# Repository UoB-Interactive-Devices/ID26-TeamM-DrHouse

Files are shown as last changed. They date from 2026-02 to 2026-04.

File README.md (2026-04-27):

# ID26-TeamM-DrHouse

## Team

<p align="center">
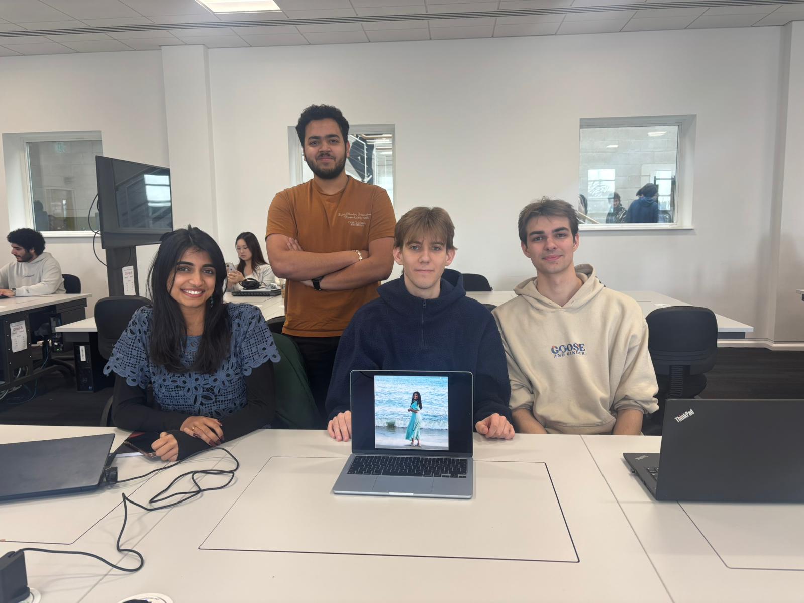
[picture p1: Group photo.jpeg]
Our team photo
  
  <br/>
  Our team photo
</p>

## Team Members
Deeksha Subramanya
<br/>
Ebin Toly
<br/>
Hugh Kiggell
<br/>
Luke Trott
<br/>
Thushi Thulasiraj

## Ideation
Window Cleaning Snail
 Image created by nano banana

Smart tap
 Image created by nano banana

Spider wall climbing robot that dusts hard to reach areas
 Image created by nano banana

## Our Interactive device
Our device is a snail that will clean and make your windows sparkling. The user charges the device. Remove the shell and fill up with water. Press the on off button at the back to start. Then simply place it on the window and it will start tracing and cleaning. The snail will have ergonomic fingerprints to encourage a correct grip. There will be a weighted hose inside the shell to spray misted water onto the window via the snail’s mouth. Once complete, the snail will beep thrice, indicating it is time to be removed.

## Design Prototype

<table>
  <tr>
    <td align="center">
      snail_cardboard1<br/>
      First prototype made of foam, not to scale.
    </td>
    <td align="center">
      snail_cardboard2
    </td>
  </tr>
</table>

<br/>

<table>
  <tr>
    <td align="center">
      snail_clay1<br/>
      Second prototype made of clay, not to scale.
    </td>
    <td align="center">
      snail_clay2<br/>
      Final design intended to be double the current size.
    </td>
  </tr>
</table>

## Questionaire

https://forms.office.com/Pages/DesignPageV2.aspx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
https://forms.office.com/Pages/DesignPageV2.aspx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

To send out: https://forms.office.com/Pages/ResponsePage.aspx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

## In person Questionaire - (Device testing)

[https://forms.office.com/Pages/DesignPageV2.aspx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](https://forms.office.com/Pages/DesignPageV2.aspx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)

To send out: https://forms.office.com/Pages/ResponsePage.aspx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

## SUS Test:

https://forms.office.com/Pages/DesignPageV2.aspx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

To send out: https://forms.office.com/Pages/ResponsePage.aspx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

## Consent Form

https://forms.office.com/Pages/DesignPageV2.aspx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

To send out: https://forms.office.com/Pages/ResponsePage.aspx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

## Risk Assesments

[Testing and Developing Rover](https://uob.sharepoint.com/:w:/r/teams/grp-grp-interactivedevices2025-2026/Shared%20Documents/Group%20M%20(Dr.%20House)%20-%20Snail%20Cleaner/Risk%20Assessment%C2%A0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)

[Demo Day](https://uob.sharepoint.com/:w:/r/teams/grp-grp-interactivedevices2025-2026/Shared%20Documents/Group%20M%20(Dr.%20House)%20-%20Snail%20Cleaner/Risk%20Assessment%C2%A0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)

## Documentation
Full report available on Overleaf check it out here:
[https://www.overleaf.com/read/fzhzwbgzmqft#be855f](https://www.overleaf.com/9472865782wmpkmnqygdsy#4a67b0)

## Video

https://uob.sharepoint.com/:v:/r/teams/grp-grp-interactivedevices2025-2026/Shared%20Documents/Group%20M%20(Dr.%20House)%20-%20Snail%20Cleaner/DrHouse_Video.MOV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

## Timeline

https://docs.google.com/document/d/1-UH61Pvg8FrAMAUsMvd9KDbhnIRM3Y1bEEfzOIujOz8/edit?usp=sharing

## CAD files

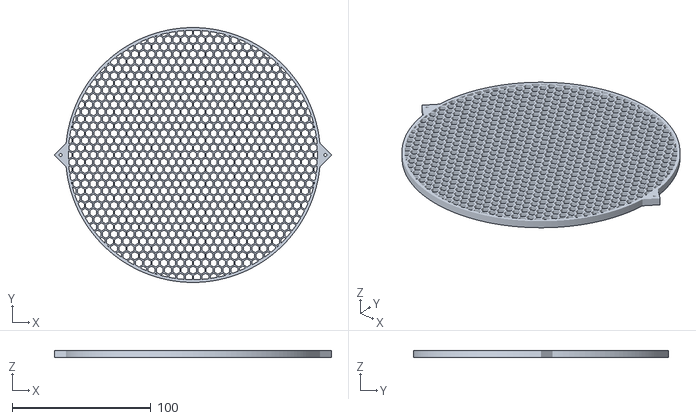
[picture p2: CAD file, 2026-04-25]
Lid.stl
200.0 x 184.0 x 5.00

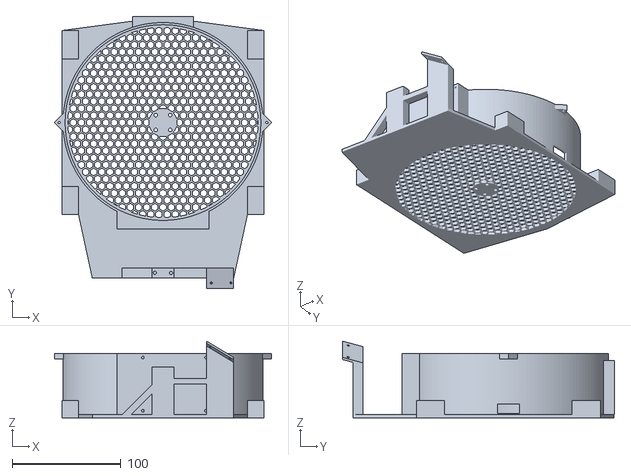
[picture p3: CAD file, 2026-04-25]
Final_Design.stl
200.0 x 250.2 x 70.6

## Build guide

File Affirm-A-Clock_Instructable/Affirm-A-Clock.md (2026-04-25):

# Instructable: Affirm-A-Clock
**Build an affirmation-based wellbeing alarm clock!**



## 1. Project Summary

Welcome to the Affirm-A-Clock project! This guide will walk you through building a Raspberry Pi-powered robotic wellness coach designed to break the "snooze" button habit and optimise your morning routine. Smartphone alarms are far too easy to ignore. - the classic snooze button actually prolongs sleep inertia, leaving you groggy and disoriented. To tackle this, Affirm-A-Clock forces you to combine physical activity with positive mental health behaviors before the alarm can be silenced. 
**How the Routine Works:** 
* **Wake Up & Move:** When the alarm triggers, you must physically get out of bed and open your curtains to experience natural sunlight. Once the alarm is stopped, the robot tells you your affirmation for the day using a Bluetooth speaker. 
* **Write an Affirmation:** You then write this positive daily affirmation directly onto your window, and underline it using dry-erase markers. 
* **Verification:** You stick the robot to the window (using fan-powered suction), where it follows the line (using HuskyLens line detection) to track your writing and confirms the completion of your handwritten task.
* **Reward & Clean:** The robot congratulates you and announces your new daily streak. Finally, you wipe the window clean, which builds a daily habit of room tidiness (which is tied to mental wellbeing). 

This guide covers the complete mechanical, electrical, and software integration required to build your own Affirm-A-Clock!

**Please Note: As this device is a proof of concept, the window suction mechanism does not yet function entirely. The assembly instructions include its installation for completeness, but strict safety measures and careful setup are required to operate it safely.  If you intend to use the propeller, ensure the safety mesh is attached, that the robot is in an enclosed space and that you are wearing protective gear (goggles, gloves, and lab coat).**

---

## 2. List of Resources Required

### Microcontrollers & Logic
* **1x** Raspberry Pi 4 (Running Raspberry Pi OS)
* **1x** DFRobot HuskyLens (AI Vision Camera)
* **1x** Bluetooth Speaker (For TTS Audio)
* **1x** ArduCam 8MP Camera V2.3

### Motors & Driving
* **1x** HW-095 Motor Controller Driver
* **4x** DC Gear Motors & Wheels (6cm diameter including tires)
* **1x** Brushless DC (BLDC) Drone Motor
* **1x** Electronic Speed Controller (ESC)
* **1x** 7" tri-blade plastic propeller
### Power & Hardware
* **1x** External power supply (6v) to power the wheel motors
* **1x** External power supply (24v) to power the propeller drone motor
* **1x** USB-c power cable to power Raspberry Pi
* Jumper wires (Female-to-Female, Male-to-Female)
* Zip-ties, hot glue or electrical tape for cable management and mounting
* Mounting screws:
	* **10x** 8mm M3 screws (Huskylens, drone motor, HW-095 motor driver)
	* **4x** 8mm M2.5 screws (Raspberry Pi 4)
	* **2x** 16mm M2 screws + M2 nuts (Protective mesh)
	* **2x** 8mm M2 screws + M2 nuts (ArduCam)
	* **1x** M3 nut (propeller)

---

## 3. Pinout & Wiring Guide

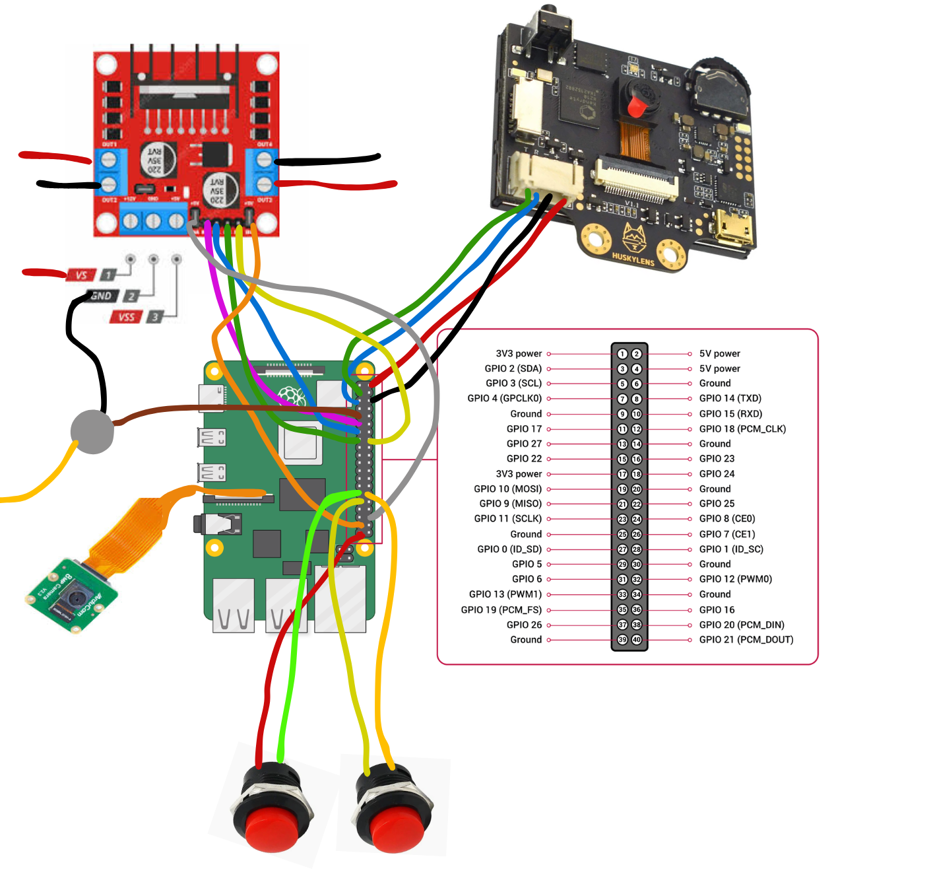
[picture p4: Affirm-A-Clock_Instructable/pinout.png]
My Pinout Diagram


For the data and PWM signals to function, the Raspberry Pi must share a **Common Ground** with both the drone motor's ESC and the HW-095 motor controller. 

### The Wiring Table

| Component | Pi Physical Pin | Pi BCM (GPIO) | Purpose |
| :--- | :--- | :--- | :--- |
| **ESC (Drone Motor)** | Pin 12 | GPIO 18 | Hardware PWM Signal (50Hz) |
| **ESC Ground** | Pin 14 | GND | Signal Ground |
| **HW-095 ENA** | Pin 32 | GPIO 12 | Right Motor PWM Speed |
| **HW-095 IN1** | Pin 33 | GPIO 13 | Right Motor Direction A |
| **HW-095 IN2** | Pin 22 | GPIO 25 | Right Motor Direction B |
| **HW-095 ENB** | Pin 37 | GPIO 26 | Left Motor PWM Speed |
| **HW-095 IN3** | Pin 13 | GPIO 27 | Left Motor Direction A |
| **HW-095 IN4** | Pin 8 | GPIO 14 | Left Motor Direction B |
| **HuskyLens SDA** | Pin 3 | GPIO 2 | I2C Data Line |
| **HuskyLens SCL** | Pin 5 | GPIO 3 | I2C Clock Line |
| **Button 1 Terminal A** | Pin 39 | GND | Button 1 Ground |
| **Button 1 Terminal B** | Pin 29 | GPIO 5 | Button 1 Signal Input |
| **Button 2 Terminal A** | Pin 31 | GPIO 6 | Button 2 Signal Input |
| **Button 2 Terminal B** | Pin 30 | GND | Button 2 Ground |

If you want to use the drone motor, ensure you use an ESC, and then connect the motor input signal to the Pi's pin 12, and add the motor's ground connection to the common ground with the pi and HW-095

---

## 5. CAD Design & Mechanical Assembly

The CAD .stl files for the robot frame and the protective lid are hosted on GitHub, accessible here:
-> **https://github.com/UoB-Interactive-Devices/ID26-TeamM-DrHouse**

### Assembly Steps:
1. **Print the Frame:** Start by 3D printing the robot frame and the protective mesh lid.
2. **Wire & Mount the Pi:** Pre-wire the Raspberry Pi 4, and then securely screw it into its mounting points on front of the frame.
3. **Attach the Cameras:** Screw the Arducam into place in its stand, and then mount the HuskyLens at the front of the frame so it has a clear view of the environment.
4. **Mount the Wheels:** Using a hot glue gun, firmly glue the DC wheel motors down onto their designated platforms on the frame.
5. **Install the Motor Controller:** Screw the HW-095 motor driver into the back of the frame. 
6. **Cable Management:** Route all of your wires and cables around the frame of the robot, ensuring they are tucked away from the wheels. You can position the buttons using glue or tape as well.
7. **Mount the Drone Motor:** Securely screw the drone motor into its designated mount in the center of the frame.
8. **Attach the Propeller & Safety Lid:** Carefully attach the propeller to the drone motor and secure using a nut. Immediately screw the protective mesh lid on top to safely enclose the propeller blades.

---

## 6. Software Setup & Configuration

### Install Dependencies
Run these commands in your terminal to install the necessary libraries for the audio engines:
```bash
sudo apt update
sudo apt install build-essential unzip python3-setuptools mpg123 sox -y
pip3 install gTTS gpiozero --break-system-packages
```
----------

## 7. The Code & Software Architecture

All the Python scripts and required libraries are hosted on GitHub. You can download the entire code repository, including the `robot_core.py` script and any necessary libraries, here:
-> **https://github.com/UoB-Interactive-Devices/ID26-TeamM-DrHouse**

### How the Robot Core Code Works
The `robot_core.py` handles hardware interrupts, local AI driving, cloud-based OCR, and Google Drive syncing. Here is a breakdown of its systems:

* **Hardware Inputs & State Management:** The script uses the `gpiozero` library to manage the physical Power and Action buttons. It runs a dedicated background thread to monitor button presses and handle debounce (so that there's only one input per one button press). 
* **Audio & TTS:** The code uses Google Text-to-Speech (`gTTS`) to generate the robot's voice, and caches the audio files locally to ensure immediate playback. To solve the issue where the Pi's audio driver 'sleeps' and misses the beginning of a sound file, the a short, silent 10Hz tone is played immediately before the real audio.
* **Driving and HuskyLens:** The Pi communicates with the HuskyLens with I2C to receive line-tracking vector data (`xHead`, `yHead`, `xTail`). The code calculates the "slant" of the line and categorises the robot into one of 5 states (e.g., straight, soft-turn, hard-correction). It then uses PWM to drive the HW-095 motor controller, adjusting the speed of the left and right wheels to follow the path.
* **Machine Vision & OCR:** While driving, a background thread uses `Picamera2` to snap photos of the floor every 0.5 seconds. Once the run finishes, the code takes these overlapping photos, stitches them together into image strips using the `PIL` (Pillow) library, boosts the contrast, and sends them to a multimodal AI model using the OpenRouter API.
* **AI Evaluation (The Judge):** Once the OCR returns the text it read from the floor, the script makes a second API call to an LLM. It passes the target affirmation and the detected text, asking the LLM to act as a lenient judge to determine a "PASS" or "FAIL", ignoring minor spelling or handwriting errors.
* **Google Drive Sync & Streak Tracking:** If you pass, the script uses the `google-auth` library to connect to your personal Google Drive. It reads the final line of an `affirmation_log.txt` file to calculate how many consecutive days you have completed the task, increments your streak by 1, and uploads the appended log back to the cloud. The robot then announces your new streak.

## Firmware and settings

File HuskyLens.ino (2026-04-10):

#include "HUSKYLENS.h"
#include "Wire.h"
#include <WiFi.h> // --- NEW: Wi-Fi Library ---

HUSKYLENS huskylens;

// ==========================================
// --- THE MASTER SWITCH ---
// Set to true for Wi-Fi. Set to false for USB Cable!
bool useWiFi = false; 
// ==========================================

// --- NEW: Wi-Fi Settings (THE ROBOT IS NOW THE ROUTER) ---
const char* ap_ssid = "Tank_Robot";
const char* ap_pass = "12345678";

// When a laptop connects to an ESP32, it almost ALWAYS gets this IP:
const char* hostIP = "192.168.4.2"; 
const uint16_t port = 5204;
WiFiClient client;

// --- Motor Wiring ---
int ENA = 32; int IN1 = 33; int IN2 = 25; 
int ENB = 14; int IN3 = 26; int IN4 = 27; 

// --- Joystick Pins ---
int joyXPin = 35; 
int joyYPin = 34; 

// --- TANK STEERING SETTINGS: THE LOW RIDER TEST ---
int autoBaseSpeed = 85;         // The absolute crawl. 

// SOFT TURNS
int autoSoftInner = 85;         // Pushing the floor!
int autoSoftOuter = 110;        // Just enough difference to steer

// HARD TURNS 
int autoHardPush = 120;         // Push forward harder into the turn!
int autoHardRev = -120;         // Pull backward gently just to help pivot

// --- Odometry Variables ---
float posX = 0.0, posY = 0.0, heading = 1.5708;
float moveDistance = 2.0; 

// --- LINE TRACKING MEMORY & DIAGNOSTICS ---
unsigned long lastDetectionTime = 0;
const unsigned long MEMORY_TIMEOUT = 200; 
int robotState = 0; // 0=Stop, 1=Strt, 2=SoftL, 3=SoftR, 4=HardL, 5=HardR

// --- NEW LOGGING VARIABLES ---
int lastTipX = 160; 
int lastSlant = 0;              
const char* activeMode = "TIP"; 

// --- NEW: WI-FI RECONNECT TIMER ---
unsigned long lastWiFiTry = 0; 

void setup() {
    Serial.begin(115200);
    
    // --- MODE SELECTION SETUP ---
    if (useWiFi) {
        Serial.println("Starting Robot Hotspot...");
        WiFi.softAP(ap_ssid, ap_pass);
        Serial.print("Robot Hotspot Created! Robot IP is: ");
        Serial.println(WiFi.softAPIP()); 
        Serial.println("Wi-Fi network is active in the background.");
    } else {
        Serial.println("Wi-Fi OFF. Using USB Serial Cable for data.");
    }

    Wire.begin(21, 22);
    Wire.setTimeOut(100);

    pinMode(ENA, OUTPUT); pinMode(IN1, OUTPUT); pinMode(IN2, OUTPUT);
    pinMode(ENB, OUTPUT); pinMode(IN3, OUTPUT); pinMode(IN4, OUTPUT);
    stopMotors();

    delay(3000); 
    while (!huskylens.begin(Wire)) {
        Serial.println("TRAPPED: Cannot find HuskyLens!"); 
        delay(1000); 
    }
    Serial.println("Tank-Steer Hybrid System Ready!");
    Serial.println("--- DIAGNOSTICS STARTED ---");
}

void loop() {
    // --- NON-BLOCKING AUTO-RECONNECT (ONLY IF WIFI IS ON) ---
    if (useWiFi && !client.connected() && (millis() - lastWiFiTry > 2000)) {
        client.connect(hostIP, port);
        lastWiFiTry = millis(); 
    }

    // 1. READ JOYSTICK
    int joyX = analogRead(joyXPin);
    int joyY = analogRead(joyYPin);
    
    int mappedX = map(joyX, 0, 4095, 180, -180); 
    int mappedY = map(joyY, 0, 4095, -180, 180);

    // 2. CHECK FOR MANUAL OVERRIDE
    if (false) { // Joystick disabled
        int leftSpeed = constrain(mappedY + mappedX, -255, 255);
        int rightSpeed = constrain(mappedY - mappedX, -255, 255);
        setLeftMotor(leftSpeed);
        setRightMotor(rightSpeed);
        robotState = 0; 
    } 
    // 3. AUTO-MODE
    else {
        if (!huskylens.request()) {
            Serial.println("I2C ERROR - Hard Resetting Bus...");
            stopMotors();
            
            Wire.end(); delay(100); 
            Wire.begin(21, 22); delay(100);
            huskylens.begin(Wire); 
        } 
        
        else if (huskylens.available()) {
            while (huskylens.available()) {
                HUSKYLENSResult result = huskylens.read();
                if (result.command == COMMAND_RETURN_ARROW) {
                    
                    int tipX = result.xTarget;
                    int tipY = result.yTarget;
                    int tailX = result.xOrigin;
                    
                    lastTipX = tipX; 
                    lastDetectionTime = millis();
                    
                    // --- THE HYBRID LOOK-AHEAD STRATEGY ---
                    if (tipY < 60) { 
                        activeMode = "TIP"; 
                        lastSlant = 0;      
                        
                        if (tipX < 100) { robotState = 4; } 
                        else if (tipX >= 100 && tipX < 150) { robotState = 2; } 
                        else if (tipX > 170 && tipX <= 220) { robotState = 3; } 
                        else if (tipX > 220) { robotState = 5; } 
                        else { robotState = 1; } 
                    } 
                    else {
                        activeMode = "VEC"; 
                        int slant = tipX - tailX; 
                        lastSlant = slant;  
                        
                        if (tipX > 250) { robotState = 5; }
                        else if (tipX < 70) { robotState = 4; }
                        else if (slant < -40) { robotState = 4; } 
                        else if (slant >= -40 && slant < -15) { robotState = 2; } 
                        else if (slant > 15 && slant <= 40) { robotState = 3; } 
                        else if (slant > 40) { robotState = 5; } 
                        else { robotState = 1; } 
                    }
                }
            }
        }

        // 4. MOTOR EXECUTION 
        if (millis() - lastDetectionTime < MEMORY_TIMEOUT) {
            
            if (robotState == 4) { 
                setLeftMotor(autoHardRev); 
                setRightMotor(autoHardPush);
                Serial.printf("[%s] TipX: %3d | Slant: %4d | HARD L | L: %4d | R: %4d\n", activeMode, lastTipX, lastSlant, autoHardRev, autoHardPush);
            } 
            else if (robotState == 2) { 
                setLeftMotor(autoSoftInner); 
                setRightMotor(autoSoftOuter);
                Serial.printf("[%s] TipX: %3d | Slant: %4d | SOFT L | L: %4d | R: %4d\n", activeMode, lastTipX, lastSlant, autoSoftInner, autoSoftOuter);
            } 
            else if (robotState == 3) { 
                setLeftMotor(autoSoftOuter);
                setRightMotor(autoSoftInner);
                Serial.printf("[%s] TipX: %3d | Slant: %4d | SOFT R | L: %4d | R: %4d\n", activeMode, lastTipX, lastSlant, autoSoftOuter, autoSoftInner);
            } 
            else if (robotState == 5) { 
                setLeftMotor(autoHardPush);
                setRightMotor(autoHardRev);
                Serial.printf("[%s] TipX: %3d | Slant: %4d | HARD R | L: %4d | R: %4d\n", activeMode, lastTipX, lastSlant, autoHardPush, autoHardRev);
            } 
            else if (robotState == 1) { 
                setLeftMotor(autoBaseSpeed);
                setRightMotor(autoBaseSpeed);
                Serial.printf("[%s] TipX: %3d | Slant: %4d | STRT   | L: %4d | R: %4d\n", activeMode, lastTipX, lastSlant, autoBaseSpeed, autoBaseSpeed);
            }
            
            // --- DEAD RECKONING ODOMETRY ---
            if (robotState == 1) { 
                posX += cos(heading) * 1.0;  
                posY += sin(heading) * 1.0; 
            } 
            else if (robotState == 2) { 
                heading += 0.002;            
                posX += cos(heading) * 0.8; 
                posY += sin(heading) * 0.8; 
            } 
            else if (robotState == 3) { 
                heading -= 0.002; 
                posX += cos(heading) * 0.8; 
                posY += sin(heading) * 0.8; 
            } 
            else if (robotState == 4) { 
                heading += 0.0075;             
            } 
            else if (robotState == 5) { 
                heading -= 0.0075; 
            }

            // ==========================================
            // --- MANUAL DATA ROUTING ---
            // ==========================================
            if (useWiFi) {
                // Send over Wi-Fi
                if (client.connected()) {
                    client.print("DATA:");
                    client.print(posX);
                    client.print(",");
                    client.println(posY);
                }
            } else {
                // Send over USB Cable
                Serial.print("DATA:");
                Serial.print(posX);
                Serial.print(",");
                Serial.println(posY);
            }
            // ==========================================
            
        } else {
            stopMotors();
            robotState = 0; 
            Serial.println("!!! CAMERA LOST LINE - MOTORS STOPPED !!!");
        }
    }
    delay(20); 
}

// --- UNIVERSAL MOTOR FUNCTIONS ---
void setLeftMotor(int speed) {
    if (speed > 0) {
        digitalWrite(IN1, HIGH); digitalWrite(IN2, LOW); analogWrite(ENA, speed);
    } else if (speed < 0) {
        digitalWrite(IN1, LOW); digitalWrite(IN2, HIGH); analogWrite(ENA, abs(speed));
    } else {
        digitalWrite(IN1, LOW); digitalWrite(IN2, LOW); analogWrite(ENA, 0);
    }
}

void setRightMotor(int speed) {
    if (speed > 0) {
        digitalWrite(IN3, HIGH); digitalWrite(IN4, LOW); analogWrite(ENB, speed);
    } else if (speed < 0) {
        digitalWrite(IN3, LOW); digitalWrite(IN4, HIGH); analogWrite(ENB, abs(speed));
    } else {
        digitalWrite(IN3, LOW); digitalWrite(IN4, LOW); analogWrite(ENB, 0);
    }
}

void stopMotors() {
    setLeftMotor(0); setRightMotor(0);
}

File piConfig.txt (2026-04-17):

[all]
# --- VIDEO & VNC FIX ---
# Enable the video driver so RealVNC has a screen to capture
dtoverlay=vc4-kms-v3d
max_framebuffers=2

# --- YOUR HARDWARE ---
# Enable I2C for your HuskyLens and Camera
dtparam=i2c_arm=on
dtparam=i2c_arm_baudrate=400000
enable_uart=1
dtoverlay=imx219

# --- PI 4 AUDIO FIX ---
dtparam=audio=on
audio_pwm_mode=2
dtoverlay=audremap,pins_12_13

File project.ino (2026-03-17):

#include <ESP32Servo.h>

Servo droneMotor;
const int escPin = 13;

const int enA = 32; const int in1 = 33; const int in2 = 25;
const int enB = 26; const int in3 = 27; const int in4 = 14;

int power = 1000; 

void setup() {
  Serial.begin(115200);
  
  pinMode(enA, OUTPUT); pinMode(in1, OUTPUT); pinMode(in2, OUTPUT);
  pinMode(enB, OUTPUT); pinMode(in3, OUTPUT); pinMode(in4, OUTPUT);
  
  droneMotor.attach(escPin, 1000, 2000);
  stopAll(); // Start all stopped
  
  Serial.println("System Arming. Wait 3s");
  delay(3000);
  Serial.println("Commands: 'G' = Go Faster, 'S' = EMERGENCY STOP");
}

void loop() {
  if (Serial.available() > 0) {
    char cmd = Serial.read();

    if (cmd == 'g' || cmd == 'G') {
      power = constrain(power + 100, 1000, 2000);
      updateMotors();
    } 
    else if (cmd == 's' || cmd == 'S') {
      stopAll();
      Serial.println("Emergency Stop");
    }
  }
}

void updateMotors() {
  droneMotor.writeMicroseconds(power);
  
  int wheelSpeed = map(power, 1000, 2000, 0, 255);
  digitalWrite(in1, HIGH); digitalWrite(in2, LOW);
  digitalWrite(in3, HIGH); digitalWrite(in4, LOW);
  analogWrite(enA, wheelSpeed);
  analogWrite(enB, wheelSpeed);
  
  Serial.print("Current Signal: "); Serial.println(power);
}

void stopAll() {
  power = 1000;
  droneMotor.writeMicroseconds(1000); // Send stop signal to ESC
  
  // Cut power to wheels
  digitalWrite(in1, LOW); digitalWrite(in2, LOW);
  digitalWrite(in3, LOW); digitalWrite(in4, LOW);
  analogWrite(enA, 0);
  analogWrite(enB, 0);
}

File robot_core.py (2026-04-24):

# -------------- IMPORTS --------------
# Standard and third-party library imports for robot operation.
# -------------------------------------
import time
import math
import os
import threading
import subprocess
import base64
import requests
import glob
import random
import datetime
import io

# -------------- GOOGLE DRIVE IMPORTS --------------
# Imports for Google Drive API and OAuth authentication.
# ---------------------------------------------------
from google.auth.transport.requests import Request
from google.oauth2.credentials import Credentials
from google_auth_oauthlib.flow import InstalledAppFlow
from googleapiclient.discovery import build
from googleapiclient.http import MediaIoBaseUpload

# -------------- HARDWARE & IMAGE LIBRARIES --------------
# Libraries for image processing, GPIO, camera, and TTS.
# --------------------------------------------------------
from concurrent.futures import ThreadPoolExecutor
from PIL import Image, ImageOps, ImageEnhance
from gpiozero import PWMOutputDevice, DigitalOutputDevice, Button
from huskylib import HuskyLensLibrary
from picamera2 import Picamera2
from gtts import gTTS


# -------------- ENVIRONMENT LOADING --------------
# Loads environment variables from a .env file if present.
# --------------------------------------------------
def load_env_file(path):
    if not os.path.exists(path):
        return
    try:
        with open(path, "r", encoding="utf-8") as f:
            for raw_line in f:
                line = raw_line.strip()
                if not line or line.startswith("#") or "=" not in line:
                    continue
                key, value = line.split("=", 1)
                key = key.strip()
                value = value.strip().strip('"').strip("'")
                if key and key not in os.environ:
                    os.environ[key] = value
    except Exception as e:
        print(f"Warning: Could not load .env file ({path}): {e}")

load_env_file(os.path.join(os.path.dirname(os.path.abspath(__file__)), ".env"))


# -------------- CONFIGURATION --------------
# Key settings and configuration for robot operation.
# --------------------------------------------
API_KEY = os.environ.get("OPENROUTER_API_KEY", "")
VISION_MODELS = [
    os.environ.get("OPENROUTER_VISION_MODEL", "qwen/qwen3-vl-32b-instruct"),
    "anthropic/claude-sonnet-4.6",
    "qwen/qwen3-vl-32b-instruct",
    "google/gemini-3-pro-image-preview",
    "openai/gpt-5-image-mini"
]
CAPTURE_INTERVAL_SEC = 0.5
STRIP_SIZE = 5
ACTION_BUTTON_PIN = int(os.environ.get("ACTION_BUTTON_PIN", "5"))
POWER_BUTTON_PIN = int(os.environ.get("POWER_BUTTON_PIN", os.environ.get("SHUTDOWN_BUTTON_PIN", "6")))
POWER_HOLD_SEC = float(os.environ.get("POWER_HOLD_SEC", os.environ.get("SHUTDOWN_HOLD_SEC", "5")))
START_BEEP_ENABLED = os.environ.get("START_BEEP_ENABLED", "1") == "1"
POWER_BUTTON_BOUNCE_SEC = float(os.environ.get("POWER_BUTTON_BOUNCE_SEC", "0.12"))
POWER_BUTTON_CONFIRM_SEC = float(os.environ.get("POWER_BUTTON_CONFIRM_SEC", "0.05"))
POWER_TAP_MIN_SEC = float(os.environ.get("POWER_TAP_MIN_SEC", "0.06"))
POWER_EVENT_COOLDOWN_SEC = float(os.environ.get("POWER_EVENT_COOLDOWN_SEC", "0.30"))
POWER_BUTTON_PULL_UP = os.environ.get("POWER_BUTTON_PULL_UP", "1") == "1"
AUDIO_MIXER_CONTROL = os.environ.get("AUDIO_MIXER_CONTROL", "PCM")
AUDIO_VOLUME_PERCENT = os.environ.get("AUDIO_VOLUME_PERCENT", "100%")
BEEP_WAKE_DURATION_SEC = float(os.environ.get("BEEP_WAKE_DURATION_SEC", "0.25"))
BEEP_WAKE_VOLUME = float(os.environ.get("BEEP_WAKE_VOLUME", "0.5"))
BEEP_SETTLE_SEC = float(os.environ.get("BEEP_SETTLE_SEC", "0.05"))
BEEP_INTERVAL_SEC = float(os.environ.get("BEEP_INTERVAL_SEC", "0.8"))

alarm_proc_lock = threading.Lock()
current_alarm_proc = None
last_alarm_started_at = 0.0
tts_cache_lock = threading.Lock()
cached_tts_text = ""
BEEP_FREQ_HZ = float(os.environ.get("BEEP_FREQ_HZ", "1200"))
BEEP_DURATION_SEC = float(os.environ.get("BEEP_DURATION_SEC", "0.18"))
BEEP_GAIN_DB = float(os.environ.get("BEEP_GAIN_DB", "12.0"))
BEEP_BURST_COUNT = int(os.environ.get("BEEP_BURST_COUNT", "2"))
BEEP_BURST_GAP_SEC = float(os.environ.get("BEEP_BURST_GAP_SEC", "0.10"))
SPEECH_WAKE_DURATION_SEC = float(os.environ.get("SPEECH_WAKE_DURATION_SEC", "0.25"))
SPEECH_WAKE_VOLUME = float(os.environ.get("SPEECH_WAKE_VOLUME", "0.5"))
SPEAKER_SETTLE_SEC = float(os.environ.get("SPEAKER_SETTLE_SEC", "0.15"))
RECENT_ALARM_SKIP_WAKE_WINDOW_SEC = float(os.environ.get("RECENT_ALARM_SKIP_WAKE_WINDOW_SEC", "8.0"))
RECENT_ALARM_SETTLE_SEC = float(os.environ.get("RECENT_ALARM_SETTLE_SEC", "0.08"))
ALARM_SOUND_PATH = os.environ.get("ALARM_SOUND_PATH", "/home/roverpi/alarm.mp3")
ALARM_MP3_PATH = "/tmp/roverpi_alarm.mp3"
SYSTEM_ALARM_PATH = "/usr/share/sounds/freedesktop/stereo/alarm-clock-elapsed.oga"
ALARM_REPEAT_COUNT = int(os.environ.get("ALARM_REPEAT_COUNT", "1"))
ALARM_REPEAT_GAP_SEC = float(os.environ.get("ALARM_REPEAT_GAP_SEC", "0.15"))
AFFIRMATION_TTS_CACHE_PATH = "/tmp/roverpi_affirmation_cache.mp3"


# -------------- GOOGLE DRIVE CONFIG --------------
# File paths and folder ID for Google Drive integration.
# --------------------------------------------------
GDRIVE_CREDS = "/home/roverpi/credentials.json"
GDRIVE_FOLDER_ID = "1xbg2vaMZ2UPwY5aEKG-ZxQxcfJb1JHYC"

def get_random_affirmation():
    try:
        with open("affirmations.txt", "r") as f:
            lines = [line.strip() for line in f if line.strip()]
        return random.choice(lines) if lines else "I am ready"
    except FileNotFoundError:
        print("Warning: affirmations.txt not found! Using fallback.")
        return "I am ready"


def play_tone_via_aplay(duration_sec, frequency_hz, wav_path, volume=None):
    try:
        # Keep audio mux routed to the speaker path used by the voice pipeline.
        try:
            subprocess.run(
                ["pinctrl", "set", "12", "a0"],
                stdout=subprocess.DEVNULL,
                stderr=subprocess.DEVNULL,
                check=False
            )
        except FileNotFoundError:
            pass

        cmd = [
            "sox", "-n", "-r", "44100", "-b", "16", "-c", "1", wav_path,
            "synth", str(duration_sec), "sine", str(frequency_hz)
        ]
        if volume is not None:
            cmd.extend(["vol", str(volume)])

        subprocess.run(
            cmd,
            stdout=subprocess.DEVNULL,
            stderr=subprocess.DEVNULL,
            check=False
        )
        if not os.path.exists(wav_path):
            return False

        subprocess.run(
            ["aplay", "-q", wav_path],
            stdout=subprocess.DEVNULL,
            stderr=subprocess.DEVNULL,
            check=False
        )
        return True
    except Exception:
        return False
    finally:
        if os.path.exists(wav_path):
            try:
                os.remove(wav_path)
            except OSError:
                pass
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

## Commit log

2026-02-09 Enhance README with device details
    Added a description of the interactive cleaning device.
2026-02-10 Update README with design prototype
    Added design prototype images for the interactive device.
2026-02-10 Revise design prototype images and add descriptions
    Updated design prototype section with new images and descriptions.
2026-02-10 Fix image formatting in README for prototypes
    Updated image syntax for design prototypes in README.
2026-02-10 Adjust image dimensions for design prototypes
    Updated image sizes for design prototypes in README.
2026-02-10 Fix formatting and update prototype descriptions
2026-02-10 Fix formatting in README for prototype descriptions
2026-02-10 Replace second prototype image in README
2026-02-16 Overleaf link added and photo layout changed
    Updated design prototype section with tables for better layout and added descriptions for each prototype.
2026-02-17 Update README with team photo and device details
    Added team photo and enhanced device description.
2026-02-17 Update README
    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
2026-03-02 Update README with team and device details
    Added team members and detailed description of the interactive device.
2026-03-02 Add ideation section to README
    Added an ideation section with an image and description of the interactive device.
2026-03-17 Initial basic code for drone motor and wheels
2026-03-26 Updated wheels/cam code and line drawing
2026-03-27 proper steering
    Need to make it detect line on whiteboard - hardware issue
    [HuskyLens.ino]
2026-04-09 Added wifi data transmission (not cable)
    Robot acts as a router -> laptopconnects to robot
2026-04-17 config for pi
    [piConfig.txt]
2026-04-25 updated drone motor stuff
    Added detailed project instructions and resource list for building the Affirm-A-Clock.
